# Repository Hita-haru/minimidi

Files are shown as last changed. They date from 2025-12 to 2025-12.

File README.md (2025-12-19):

# Little mini midi
## Description of this project.
This is my first midi keyboard.  
I used to https://blueprint.hackclub.com/starter-projects/midi as a reference.  

I was thinking I wish I could making songs with midi keyboard that graphical and useful.
So I maked this midi keyboard.

## Screenshots
Schematic  
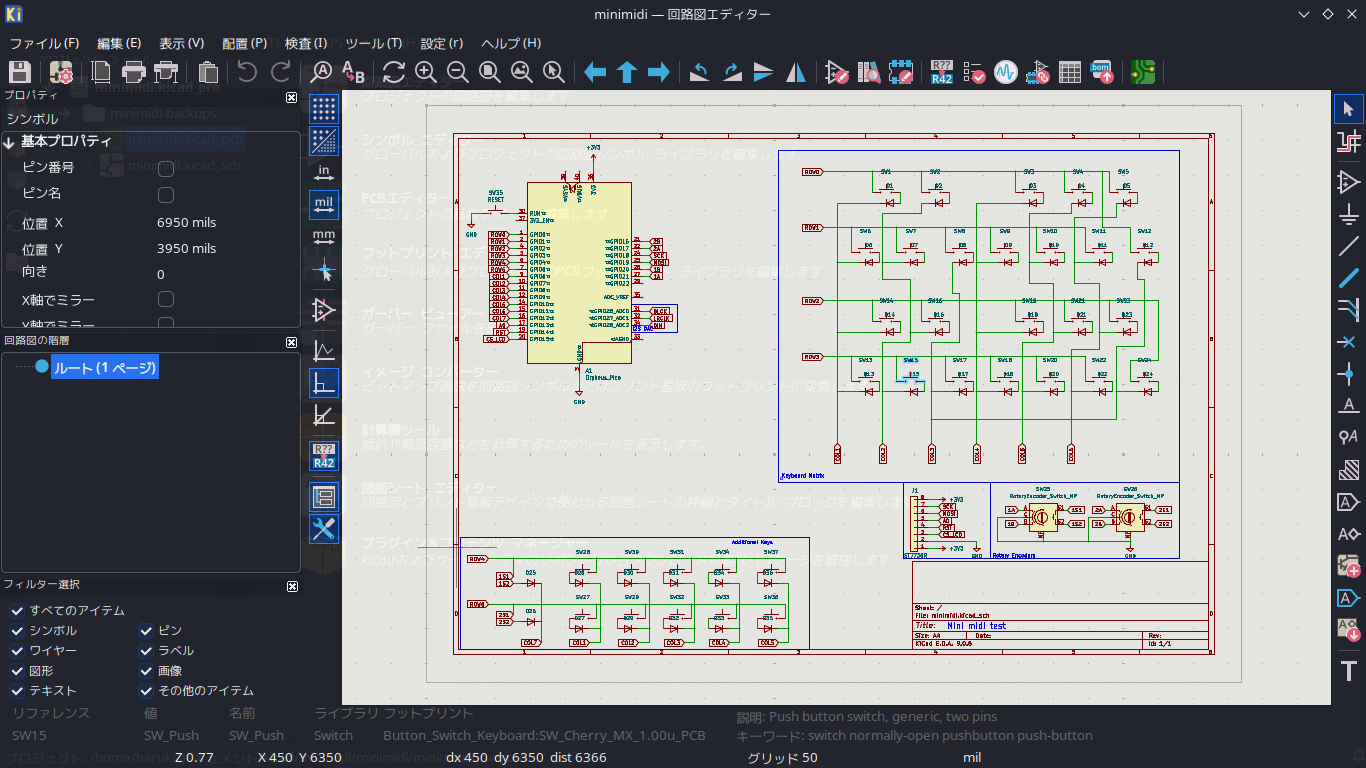
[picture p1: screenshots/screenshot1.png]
Kicad schematic screenshot
  
PCB(Layout)  
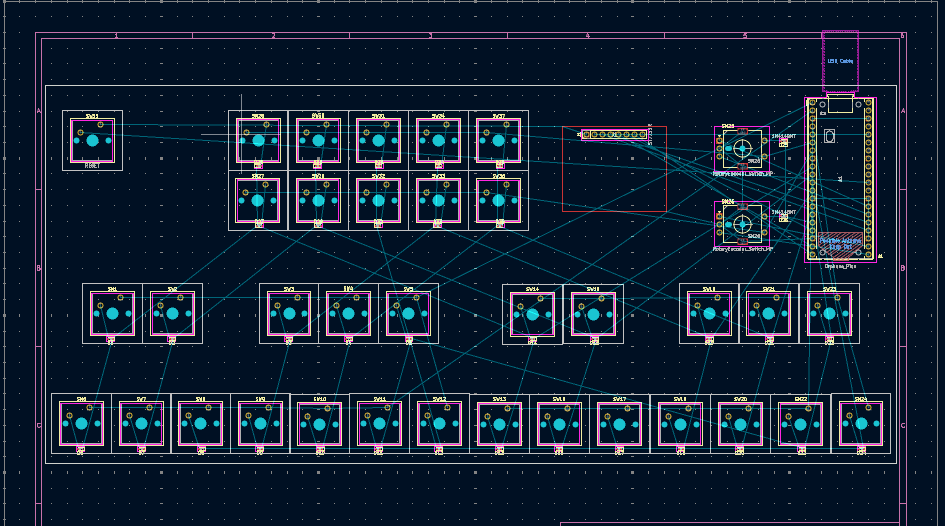
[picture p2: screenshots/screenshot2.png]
Kicad PCB screenshot
  
PCB(Final version)  
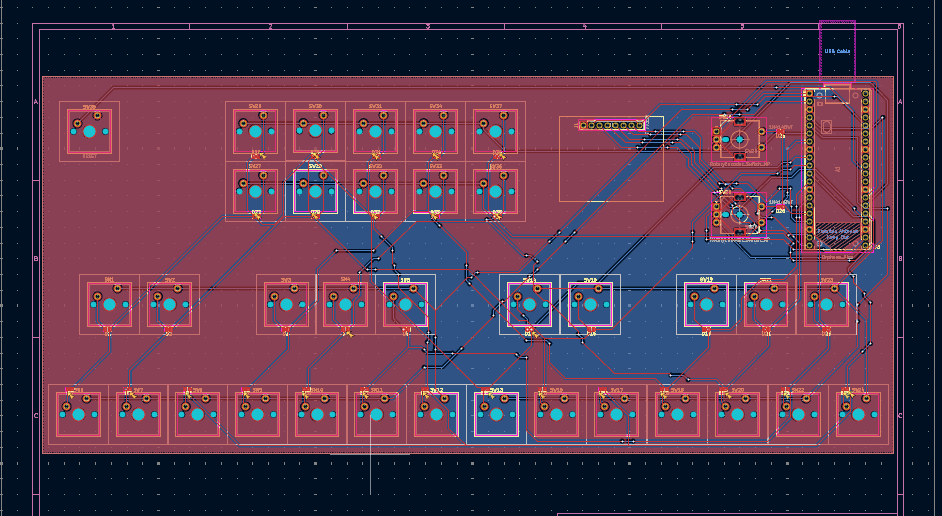
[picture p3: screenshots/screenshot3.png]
Kicad PCB screenshot
  
Programming  
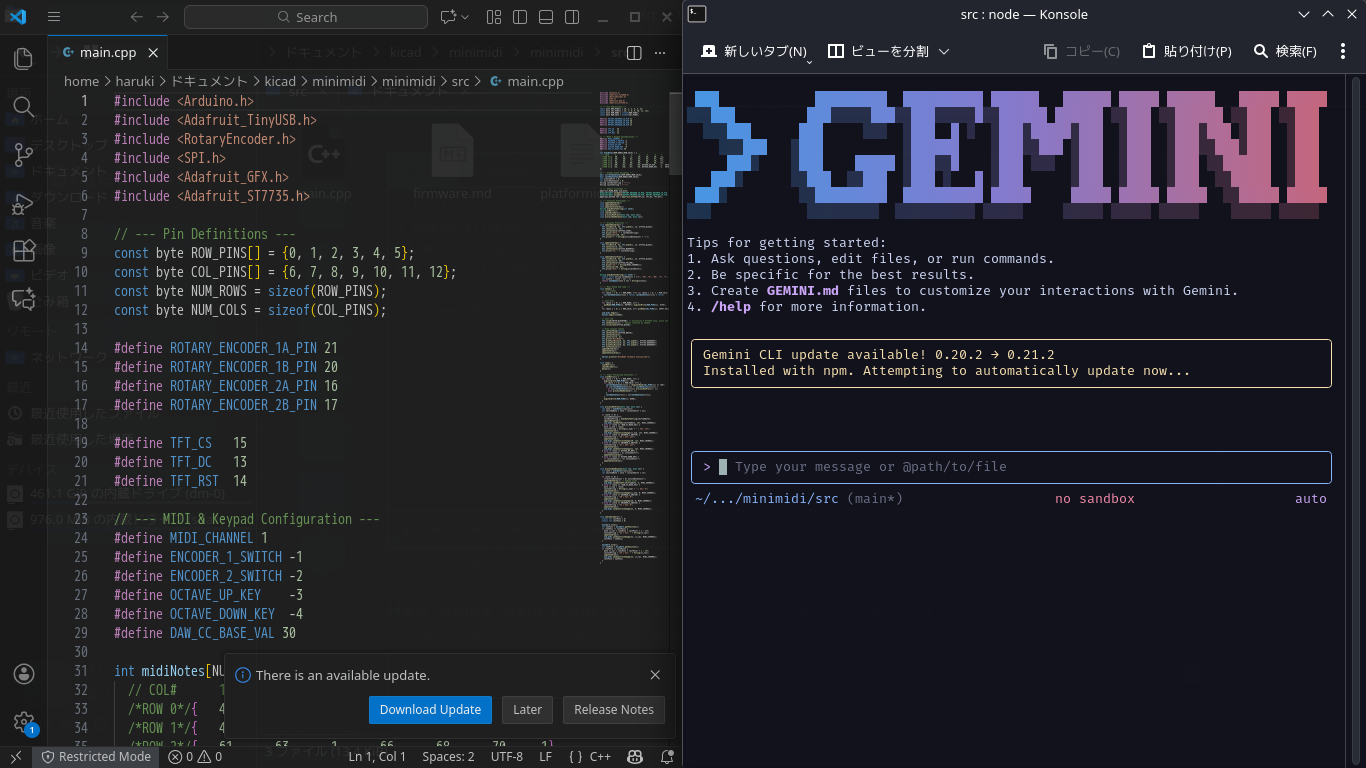
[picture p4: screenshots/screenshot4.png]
Programming
  
## Estimates
JLCPCB Estimate  
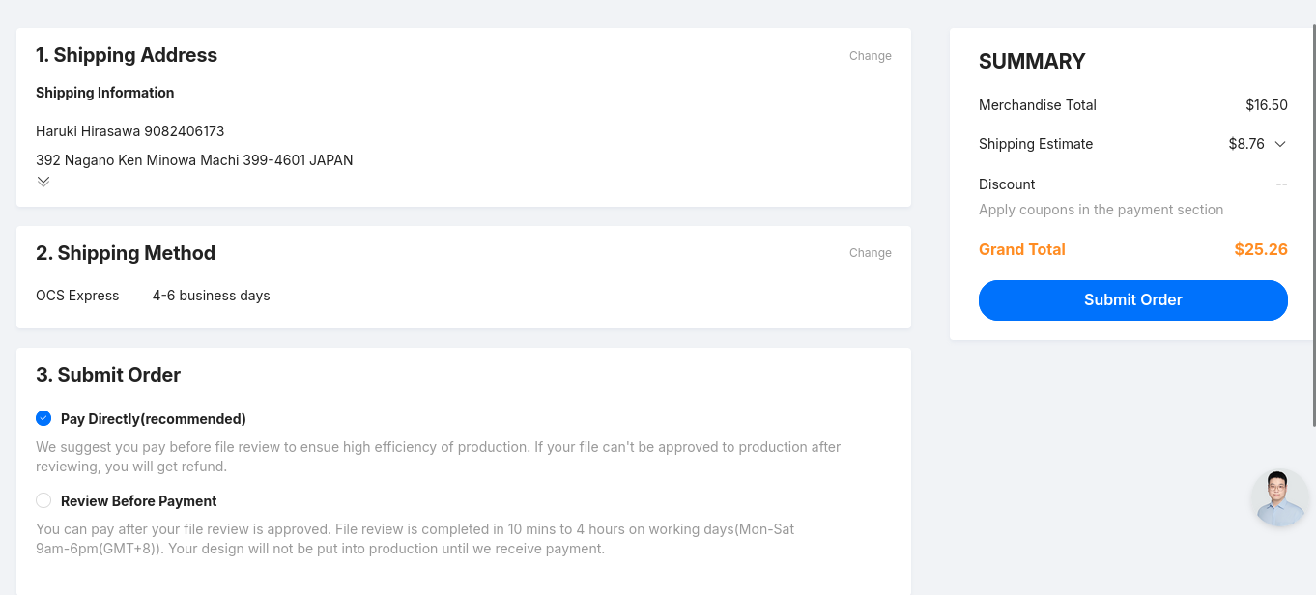
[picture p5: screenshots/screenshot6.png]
JLCPCB Estimate
  
LCSC Estimate  
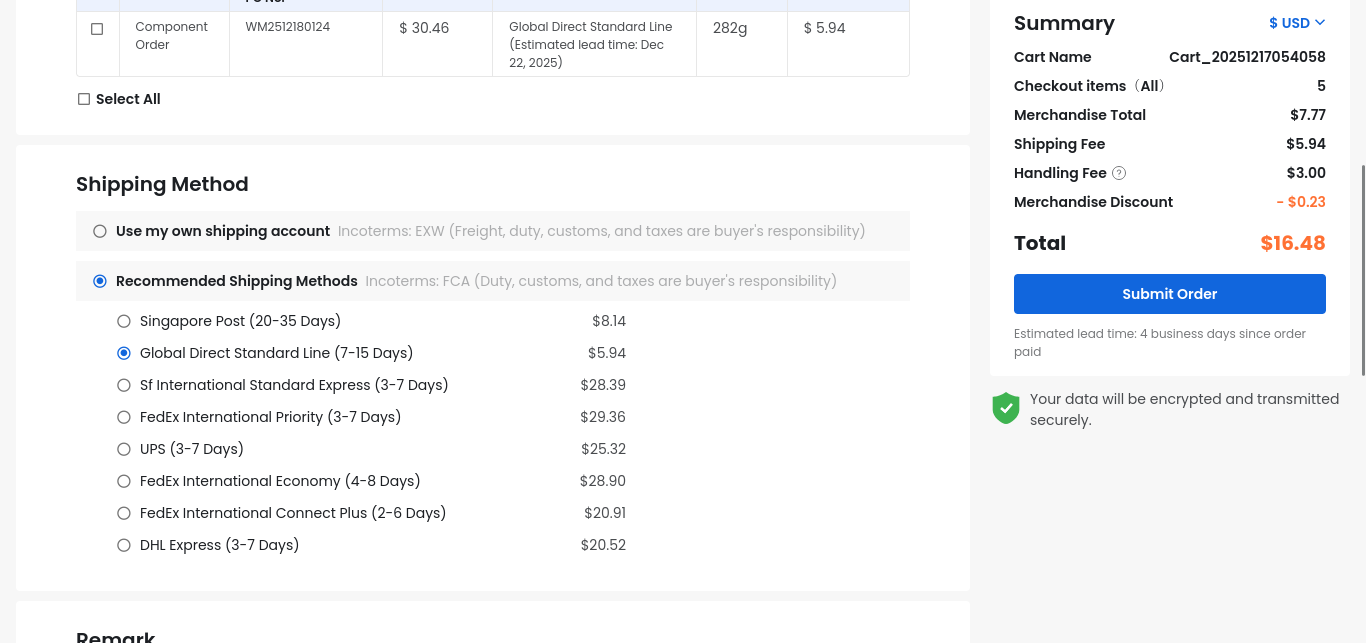
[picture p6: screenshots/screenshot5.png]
LCSC Estimate
  

## BOM
|Name |Quantity|
|---|---|
|Cherry MX Key  |35 |
|PinHeader 1x08 |1 |
|Diode |36 |
|RotaryEncoder  |2 |
|RP Pi Pico |1 |
|PinHeader 1x20 |2 |

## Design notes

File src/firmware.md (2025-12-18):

# MiniMIDIキーボード ファームウェアガイド

## 1. 概要

このドキュメントは、orpheus pico (Raspberry Pi Pico互換機) を使用した自作MIDIキーボードのファームウェアに関する使い方や仕様を説明するものです。

このファームウェアは以下の機能を持ちます:
- 4オクターブ範囲のMIDIノート出力
- オクターブUP/DOWN機能
- DAWコントロール用のMIDI CCボタン
- 2つのロータリーエンコーダーによるMIDI CC出力
- 操作内容をリアルタイムで表示するLCDディスプレイ機能

## 2. 必要なもの

### ハードウェア
- orpheus pico (またはRaspberry Pi Pico互換機)
- このプロジェクト用に作成されたキーボード基板
- ST7735 LCDディスプレイ
- PCと接続するためのUSBケーブル

### ソフトウェア
- [Visual Studio Code](https://code.visualstudio.com/)
- [PlatformIO IDE 拡張機能](https://platformio.org/platformio-ide)

## 3. インストールとファームウェアの書き込み

1.  **プロジェクトを開く**:
    Visual Studio Codeを起動し、「ファイル」>「フォルダーを開く...」からこのプロジェクトのディレクトリを選択します。

2.  **ライブラリの自動インストール**:
    プロジェクトを初めて開くと、PlatformIOが設定ファイル (`platformio.ini`) を読み込み、必要なライブラリ（USB MIDI、エンコーダー、LCDライブラリなど）を自動的にダウンロード・インストールします。

3.  **ファームウェアの書き込み**:
    - Picoの「BOOTSEL」ボタンを押しながら、PCにUSBケーブルで接続します。
    - VS Codeのターミナル（「ターミナル」>「新しいターミナル」）を開き、以下のコマンドを実行します。

    ```bash
    pio run --target upload
    ```
    - コンパイルと書き込みが自動的に実行されます。書き込みが完了すると、PicoはMIDIキーボードとしてPCに認識されます。

## 4. 機能と使い方

### キーボードとMIDIノート

- **鍵盤レイアウト**:
  - `ROW 0` & `ROW 2`: 黒鍵 (低オクターブ/高オクターブ)
  - `ROW 1` & `ROW 3`: 白鍵 (低オクターブ/高オクターブ)
- **オクターブ変更**:
  - **オクターブUP**: `ROW4, COL5` のキーを押します。 (最大+2)
  - **オクターブDOWN**: `ROW5, COL5` のキーを押します。 (最小-2)
  - 現在のオクターブ設定はLCDの下段に `Oct: ` として表示されます。

### DAWコントロールキー (MIDI CC)

`ROW4`と`ROW5`のキーは、DAWの機能を操作するためのコントロールチェンジ(CC)メッセージを送信します。キーを押している間ON (値:127)、離すとOFF (値:0) となるモーメンタリボタンとして機能します。

| キー (行, 列) | 送信されるCC番号 | 用途の例 |
| :--- | :--- | :--- |
| `ROW4, COL1` | CC 30 | トラック1のミュート/ソロ/録音アーム |
| `ROW4, COL2` | CC 31 | トラック2のミュート/ソロ/録音アーム |
| `ROW4, COL3` | CC 32 | トラック3のミュート/ソロ/録音アーム |
| `ROW4, COL4` | CC 33 | トラック4のミュート/ソロ/録音アーム |
| `ROW5, COL1` | CC 35 | トランスポート: 再生 |
| `ROW5, COL2` | CC 36 | トランスポート: 停止 |
| `ROW5, COL3` | CC 37 | トランスポート: 録音 |
| `ROW5, COL4` | CC 38 | メトロノーム ON/OFF |

### ロータリーエンコーダー

2つのエンコーダーは、回転と押し込みでCCメッセージを送信します。

| 操作 | 送信されるCC番号 | 値 | 用途の例 |
| :--- | :--- | :--- | :--- |
| **エンコーダー1 (上) 回転**  | CC 22 | 時計回り: 1, 反時計回り: 127 | 選択トラックのボリューム/パン調整 |
| **エンコーダー1 (上) 押込**  | CC 20 | 押した時: 127, 離した時: 0 | 選択トラックのミュート切り替え |
| **エンコーダー2 (下) 回転**  | CC 23 | 時計回り: 1, 反時計回り: 127 | マスターボリューム/パン調整 |
| **エンコーダー2 (下) 押込**  | CC 21 | 押した時: 127, 離した時: 0 | マスターミュート/エフェクトON/OFF |

### LCD情報パネル

LCDには3つのエリアがあり、リアルタイムで情報が更新されます。

- **上段 (Note)**: 最後に押したMIDIノート名と、現在同時に押されているキーの数を表示します。
  - 例: `Note: C#4 (2)`
- **中段 (CC)**: 最後に操作したエンコーダーやボタンのCC情報を表示します。
  - 例: `CC: 22 | Val: 1`
- **下段 (Status)**: 現在のMIDIチャンネルとオクターブ設定を表示します。
  - 例: `Ch:1 Oct:0`

## 5. トラブルシューティング

- **LCDが表示されない、または表示がおかしい**:
  ST7735 LCDにはいくつかの種類があります。`src/main.cpp`の`setup()`関数内にある以下の行を修正してみてください。
  ```cpp
  // この行の...
  tft.initR(INITR_BLACKTAB);
  
  // INITR_BLACKTAB の部分を、お使いのLCDに合わせて以下のように変更
  // tft.initR(INITR_GREENTAB);
  // tft.initR(INITR_REDTAB);
  ```
  また、画面の向きが正しくない場合は、すぐ下にある `tft.setRotation(1);` の数値を `0`, `2`, `3` のいずれかに変更して試してください。

- **キーやエンコーダーの動作がおかしい**:
  以下のコマンドでシリアルモニターを起動すると、PC側で詳細なデバッグログを確認できます。
  ```bash
  pio device monitor
  ```
  これにより、どのキーが認識され、どのようなMIDIメッセージが生成されているかを追跡できます。

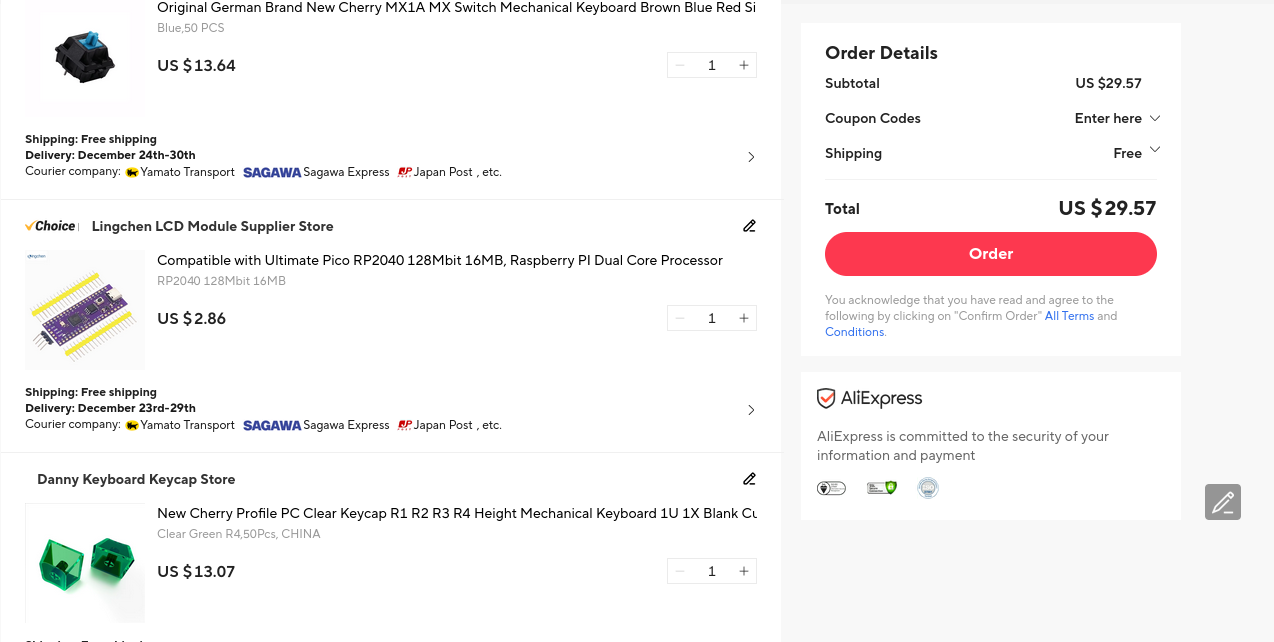
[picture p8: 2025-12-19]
screenshots/screenshot7.png

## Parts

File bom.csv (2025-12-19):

ID | 指定子 | フットプリント | 数量 | 名称 | 供給業者、参考資料
1 | SW28,SW33,SW24,SW13,SW32,SW12,SW31,SW19,SW20,SW30,SW23,SW16,SW17,SW6,SW21,SW27,SW10,SW3,SW34,SW14,SW11,SW36,SW18,SW1,SW8,SW9,SW15,SW7,SW22,SW5,SW37,SW4,SW2,SW29 | SW_Cherry_MX_1.00u_PCB | 34 | SW_Push
2 | D21,D3,D22,D29,D35,D5,D25,D15,D17,D30,D24,D4,D34,D26,D19,D6,D36,D10,D28,D2,D12,D20,D31,D23,D18,D33,D32,D11,D13,D9,D14,D27,D16,D8,D1,D7 | D_SOD-523 | 36 | 1N4148WT
3 | SW25,SW26 | RotaryEncoder_Alps_EC11E-Switch_Vertical_H20mm_MountingHoles | 2 | RotaryEncoder_Switch_MP
4 | J1 | PinHeader_1x08_P2.54mm_Vertical | 1 | ST7735R
5 | SW35 | SW_Cherry_MX_1.00u_PCB | 1 | RESET
6 | A1 | RaspberryPi_Pico_Common_THT | 1 | Orpheus_Pico
7 |  | Key_cap | 35
7 |  | PinHeader_1x20;2;;

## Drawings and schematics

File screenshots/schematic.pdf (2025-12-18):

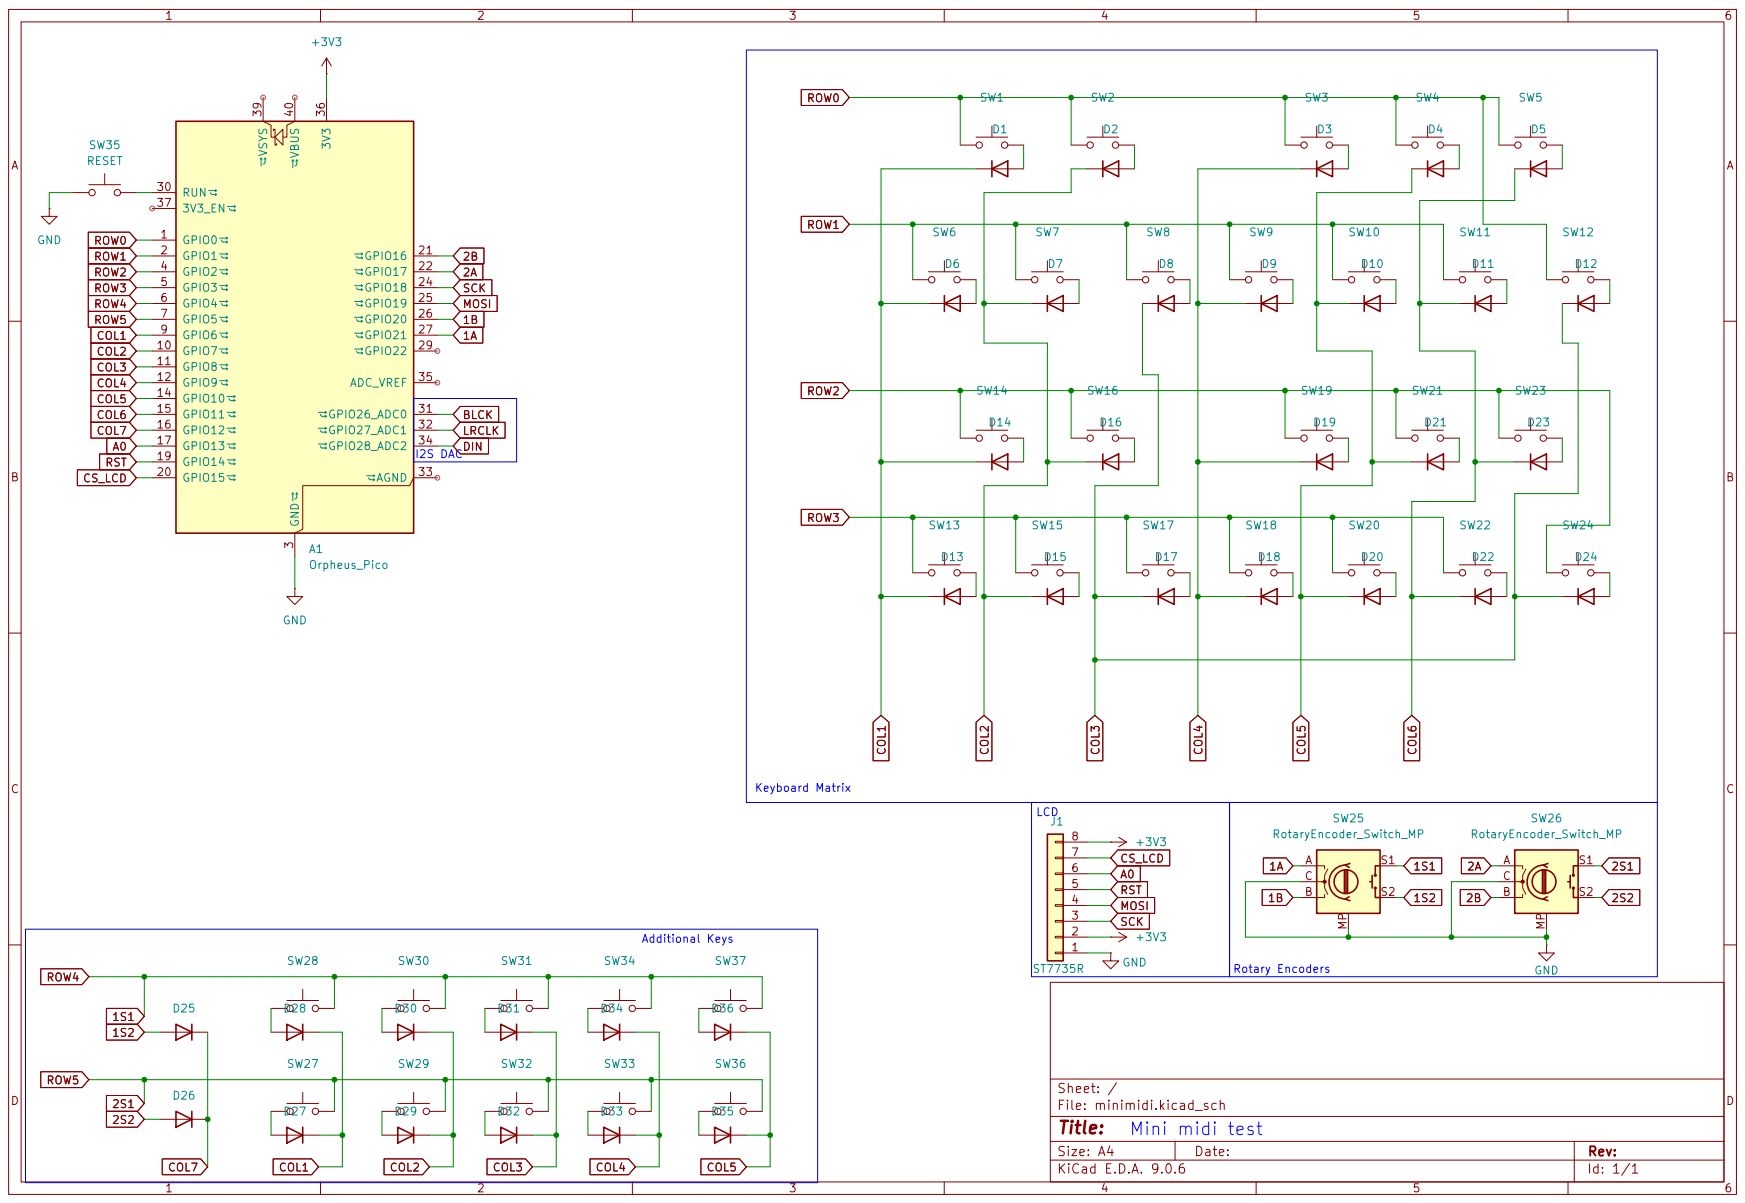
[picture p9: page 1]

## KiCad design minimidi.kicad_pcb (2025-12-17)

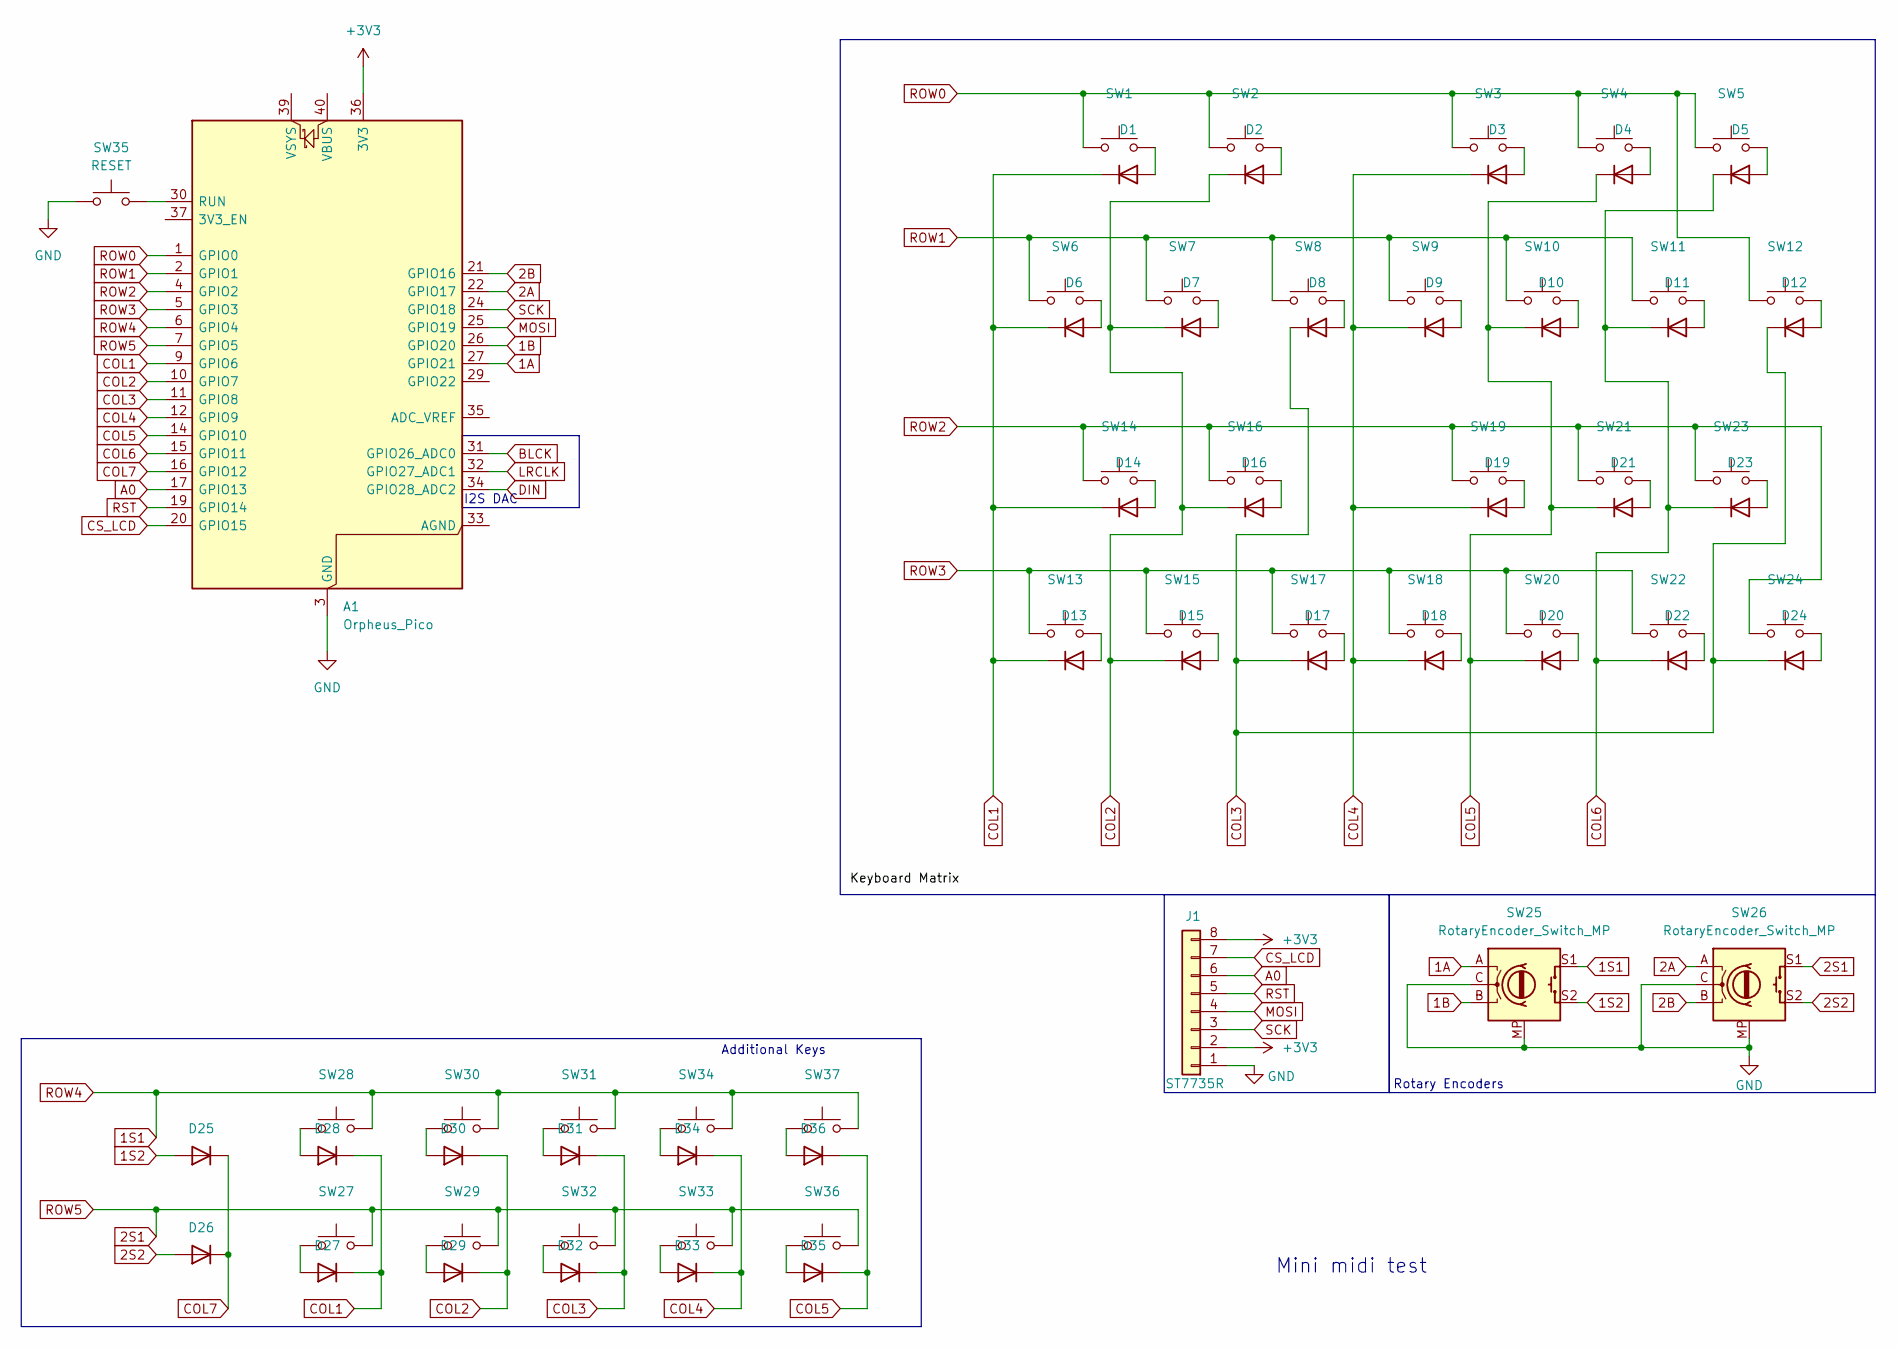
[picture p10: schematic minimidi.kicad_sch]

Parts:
A1: Orpheus_Pico; RaspberryPi_Pico_Common_THT
D1, D2, D3, D4, D5, D6, D7, D8, D9, D10, D11, D12, D13, D14, D15, D16, D17, D18, D19, D20, D21, D22, D23, D24, D25, D26, D27, D28, D29, D30, D31, D32, D33, D34, D35, D36: 1N4148WT; D_SOD-523
J1: ST7735R; PinHeader_1x08_P2.54mm_Vertical
SW1, SW2, SW3, SW4, SW5, SW6, SW7, SW8, SW9, SW10, SW11, SW12, SW13, SW14, SW15, SW16, SW17, SW18, SW19, SW20, SW21, SW22, SW23, SW24, SW27, SW28, SW29, SW30, SW31, SW32, SW33, SW34, SW36, SW37: SW_Push; SW_Cherry_MX_1.00u_PCB
SW25, SW26: RotaryEncoder_Switch_MP; RotaryEncoder_Alps_EC11E-Switch_Vertical_H20mm_MountingHoles
SW35: RESET; SW_Cherry_MX_1.00u_PCB

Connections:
1A: A1.27 (GPIO21), SW25.A
1B: A1.26 (GPIO20), SW25.B
1S1: A1.6 (GPIO4), SW25.S1, SW28.2, SW30.2, SW31.2, SW34.2, SW37.2
1S2: D25.2 (A), SW25.S2
2A: A1.22 (GPIO17), SW26.A
2B: A1.21 (GPIO16), SW26.B
2S1: A1.7 (GPIO5), SW26.S1, SW27.2, SW29.2, SW32.2, SW33.2, SW36.2
2S2: D26.2 (A), SW26.S2
+3V3: A1.36 (3V3), J1.2, J1.8
A0: A1.17 (GPIO13), J1.6
BLCK: A1.31 (GPIO26_ADC0)
COL1: A1.9 (GPIO6), D1.1 (K), D6.1 (K), D13.1 (K), D14.1 (K), D27.1 (K), D28.1 (K)
COL2: A1.10 (GPIO7), D2.1 (K), D7.1 (K), D15.1 (K), D16.1 (K), D29.1 (K), D30.1 (K)
COL3: A1.11 (GPIO8), D8.1 (K), D12.1 (K), D17.1 (K), D24.1 (K), D31.1 (K), D32.1 (K)
COL4: A1.12 (GPIO9), D3.1 (K), D9.1 (K), D18.1 (K), D19.1 (K), D33.1 (K), D34.1 (K)
COL5: A1.14 (GPIO10), D4.1 (K), D10.1 (K), D20.1 (K), D21.1 (K), D35.1 (K), D36.1 (K)
COL6: A1.15 (GPIO11), D5.1 (K), D11.1 (K), D22.1 (K), D23.1 (K)
COL7: A1.16 (GPIO12), D25.1 (K), D26.1 (K)
CS_LCD: A1.20 (GPIO15), J1.7
DIN: A1.34 (GPIO28_ADC2)
GND: A1.3 (GND), A1.8 (GND), A1.13 (GND), A1.18 (GND), A1.23 (GND), A1.28 (GND), A1.38 (GND), J1.1, SW25.C, SW25.MP, SW26.C, SW26.MP, SW35.1
LRCLK: A1.32 (GPIO27_ADC1)
MOSI: A1.25 (GPIO19), J1.4
unnamed: A1.30 (RUN), SW35.2
unnamed: D1.2 (A), SW1.2
unnamed: D2.2 (A), SW2.2
unnamed: D3.2 (A), SW3.2
unnamed: D4.2 (A), SW4.2
unnamed: D5.2 (A), SW5.2
unnamed: D6.2 (A), SW6.2
unnamed: D7.2 (A), SW7.2
unnamed: D8.2 (A), SW8.2
unnamed: D9.2 (A), SW9.2
unnamed: D10.2 (A), SW10.2
unnamed: D11.2 (A), SW11.2
unnamed: D12.2 (A), SW12.2
unnamed: D13.2 (A), SW13.2
unnamed: D14.2 (A), SW14.2
unnamed: D15.2 (A), SW15.2
unnamed: D16.2 (A), SW16.2
unnamed: D17.2 (A), SW17.2
unnamed: D18.2 (A), SW18.2
unnamed: D19.2 (A), SW19.2
unnamed: D20.2 (A), SW20.2
unnamed: D21.2 (A), SW21.2
unnamed: D22.2 (A), SW22.2
unnamed: D23.2 (A), SW23.2
unnamed: D24.2 (A), SW24.2
unnamed: D27.2 (A), SW27.1
unnamed: D28.2 (A), SW28.1
unnamed: D29.2 (A), SW29.1
unnamed: D30.2 (A), SW30.1
unnamed: D31.2 (A), SW31.1
unnamed: D32.2 (A), SW32.1
unnamed: D33.2 (A), SW33.1
unnamed: D34.2 (A), SW34.1
unnamed: D35.2 (A), SW36.1
unnamed: D36.2 (A), SW37.1
ROW0: A1.1 (GPIO0), SW1.1, SW2.1, SW3.1, SW4.1, SW5.1, SW12.1
ROW1: A1.2 (GPIO1), SW6.1, SW7.1, SW8.1, SW9.1, SW10.1, SW11.1
ROW2: A1.4 (GPIO2), SW14.1, SW16.1, SW19.1, SW21.1, SW23.1, SW24.1
ROW3: A1.5 (GPIO3), SW13.1, SW15.1, SW17.1, SW18.1, SW20.1, SW22.1
RST: A1.19 (GPIO14), J1.5
SCK: A1.24 (GPIO18), J1.3

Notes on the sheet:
Mini midi test
I2S DAC
Additional Keys
Rotary Encoders

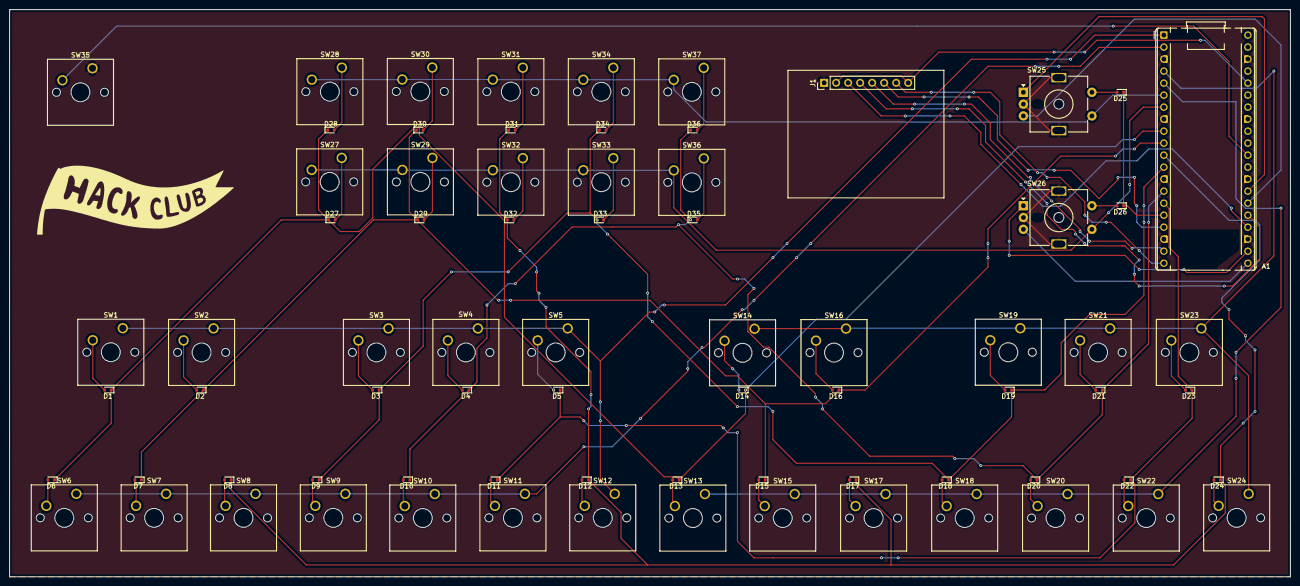
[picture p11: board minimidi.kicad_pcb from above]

Board: 2 copper layers, 271.0 x 120.0 mm, 75 parts (0 on the bottom side), 61 nets.

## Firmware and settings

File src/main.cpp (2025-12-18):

#include <Arduino.h>
#include <Adafruit_TinyUSB.h>
#include <RotaryEncoder.h>
#include <SPI.h>
#include <Adafruit_GFX.h>
#include <Adafruit_ST7735.h>

// --- Pin Definitions ---
const byte ROW_PINS[] = {0, 1, 2, 3, 4, 5};
const byte COL_PINS[] = {6, 7, 8, 9, 10, 11, 12};
const byte NUM_ROWS = sizeof(ROW_PINS);
const byte NUM_COLS = sizeof(COL_PINS);

#define ROTARY_ENCODER_1A_PIN 21
#define ROTARY_ENCODER_1B_PIN 20
#define ROTARY_ENCODER_2A_PIN 16
#define ROTARY_ENCODER_2B_PIN 17

#define TFT_CS   15
#define TFT_DC   13
#define TFT_RST  14

// --- MIDI & Keypad Configuration ---
#define MIDI_CHANNEL 1
#define ENCODER_1_SWITCH -1
#define ENCODER_2_SWITCH -2
#define OCTAVE_UP_KEY    -3
#define OCTAVE_DOWN_KEY  -4
#define DAW_CC_BASE_VAL 30

int midiNotes[NUM_ROWS][NUM_COLS] = {
  // COL#      1,      2,      3,      4,      5,      6,    7
  /*ROW 0*/{   49,     51,    -1,     54,     56,     58,   -1},
  /*ROW 1*/{   48,     50,    52,     53,     55,     57,   59},
  /*ROW 2*/{   61,     63,    -1,     66,     68,     70,   -1},
  /*ROW 3*/{   60,     62,    64,     65,     67,     69,   71},
  /*ROW 4*/{  -30,    -31,   -32,    -33, OCTAVE_UP_KEY,    -1,  ENCODER_1_SWITCH},
  /*ROW 5*/{  -35,    -36,   -37,    -38, OCTAVE_DOWN_KEY,  -1,  ENCODER_2_SWITCH}
};

// --- Global State Variables ---
bool currentKeyStates[NUM_ROWS][NUM_COLS];
bool lastKeyStates[NUM_ROWS][NUM_COLS];
int octaveShift = 0;
int activeNoteCount = 0;
String lastNoteString = "---";
String lastCCString = "---";

// --- Object Instances ---
Adafruit_USBD_MIDI usb_midi;
RotaryEncoder encoder1(ROTARY_ENCODER_1A_PIN, ROTARY_ENCODER_1B_PIN, RotaryEncoder::LatchMode::FOUR3);
RotaryEncoder encoder2(ROTARY_ENCODER_2A_PIN, ROTARY_ENCODER_2B_PIN, RotaryEncoder::LatchMode::FOUR3);
Adafruit_ST7735 tft = Adafruit_ST7735(TFT_CS, TFT_DC, TFT_RST);

// --- Function Prototypes ---
void updateNoteArea();
void updateCCArea();
void updateStatusArea();
String midiNoteToString(int note);
void scanMatrix();
void checkEncoders();
void processKeyPress(byte row, byte col);
void processKeyRelease(byte row, byte col);


// --- Display Functions ---
void updateNoteArea() {
  tft.fillRect(0, 25, tft.width(), 12, ST7735_BLACK);
  tft.setCursor(5, 25);
  tft.setTextColor(ST7735_CYAN);
  tft.print("Note: " + lastNoteString);
  tft.setCursor(110, 25);
  tft.print("(" + String(activeNoteCount) + ")");
}

void updateCCArea() {
  tft.fillRect(0, 55, tft.width(), 12, ST7735_BLACK);
  tft.setCursor(5, 55);
  tft.setTextColor(ST7735_MAGENTA);
  tft.print("CC: " + lastCCString);
}

void updateStatusArea() {
  tft.fillRect(0, 85, tft.width(), 12, ST7735_BLACK);
  tft.setCursor(5, 85);
  tft.setTextColor(ST7735_YELLOW);
  tft.print("Ch:" + String(MIDI_CHANNEL));
  tft.setCursor(80, 85);
  tft.print("Oct:" + String(octaveShift));
}

String midiNoteToString(int note) {
  static const String noteNames[] = {"C", "C#", "D", "D#", "E", "F", "F#", "G", "G#", "A", "A#", "B"};
  int octave = (note / 12) - 1;
  return noteNames[note % 12] + String(octave);
}

// --- Main Setup and Loop ---
void setup() {
  // Init states
  for (byte r = 0; r < NUM_ROWS; r++) for (byte c = 0; c < NUM_COLS; c++) {
    currentKeyStates[r][c] = false; lastKeyStates[r][c] = false;
  }
  
  // Init Pins
  for (byte i = 0; i < NUM_ROWS; i++) {
    pinMode(ROW_PINS[i], OUTPUT); digitalWrite(ROW_PINS[i], HIGH);
  }
  for (byte i = 0; i < NUM_COLS; i++) pinMode(COL_PINS[i], INPUT_PULLUP);

  usb_midi.begin();
  Serial.begin(115200);

  // Init LCD
  tft.initR(INITR_BLACKTAB); // Initialize a ST7735S chip, black tab
  tft.setRotation(1); // Adjust rotation as needed
  tft.fillScreen(ST7735_BLACK);

  // Draw initial layout
  tft.setTextWrap(false);
  tft.setTextColor(ST7735_WHITE);
  tft.setTextSize(2);
  tft.setCursor(5, 5);
  tft.print("MiniMIDI");
  tft.drawFastHLine(0, 22, tft.width(), ST7735_DARKGREY);
  tft.drawFastHLine(0, 52, tft.width(), ST7735_DARKGREY);
  tft.drawFastHLine(0, 82, tft.width(), ST7735_DARKGREY);
  tft.setTextSize(1);
  updateNoteArea();
  updateCCArea();
  updateStatusArea();
  
  Serial.println("MiniMIDI Firmware Initialized");
}

void loop() {
  scanMatrix();
  checkEncoders();
  delay(1); 
}

// --- Input Processing Functions ---
void scanMatrix() {
  for (byte r = 0; r < NUM_ROWS; r++) {
    digitalWrite(ROW_PINS[r], LOW);
    for (byte c = 0; c < NUM_COLS; c++) {
      currentKeyStates[r][c] = (digitalRead(COL_PINS[c]) == LOW);
      if (currentKeyStates[r][c] != lastKeyStates[r][c]) {
        if (currentKeyStates[r][c]) processKeyPress(r, c);
        else processKeyRelease(r, c);
      }
      lastKeyStates[r][c] = currentKeyStates[r][c];
    }
    digitalWrite(ROW_PINS[r], HIGH);
  }
}

void processKeyPress(byte row, byte col) {
  int note = midiNotes[row][col];
  int shiftedNote = note + (octaveShift * 12);

  if (note >= 0) {
    activeNoteCount++;
    lastNoteString = midiNoteToString(shiftedNote);
    updateNoteArea();
    usb_midi.sendNoteOn(shiftedNote, 127, MIDI_CHANNEL);
  } else if (note <= -DAW_CC_BASE_VAL) {
    byte cc_num = -note;
    lastCCString = String(cc_num) + " | Val: 127";
    updateCCArea();
    usb_midi.sendControlChange(cc_num, 127, MIDI_CHANNEL);
  } else if (note == ENCODER_1_SWITCH) {
    lastCCString = "20 | Val: 127";
    updateCCArea();
    usb_midi.sendControlChange(20, 127, MIDI_CHANNEL);
  } else if (note == ENCODER_2_SWITCH) {
    lastCCString = "21 | Val: 127";
    updateCCArea();
    usb_midi.sendControlChange(21, 127, MIDI_CHANNEL);
  } else if (note == OCTAVE_UP_KEY) {
    if (octaveShift < 2) octaveShift++;
    updateStatusArea();
  } else if (note == OCTAVE_DOWN_KEY) {
    if (octaveShift > -2) octaveShift--;
    updateStatusArea();
  }
}

void processKeyRelease(byte row, byte col) {
  int note = midiNotes[row][col];
  int shiftedNote = note + (octaveShift * 12);

  if (note >= 0) {
    if(activeNoteCount > 0) activeNoteCount--;
    updateNoteArea(); // Update count
    usb_midi.sendNoteOff(shiftedNote, 0, MIDI_CHANNEL);
  } else if (note <= -DAW_CC_BASE_VAL) {
    byte cc_num = -note;
    lastCCString = String(cc_num) + " | Val: 0";
    updateCCArea();
    usb_midi.sendControlChange(cc_num, 0, MIDI_CHANNEL);
  } else if (note == ENCODER_1_SWITCH) {
    lastCCString = "20 | Val: 0";
    updateCCArea();
    usb_midi.sendControlChange(20, 0, MIDI_CHANNEL);
  } else if (note == ENCODER_2_SWITCH) {
    lastCCString = "21 | Val: 0";
    updateCCArea();
    usb_midi.sendControlChange(21, 0, MIDI_CHANNEL);
  }
}

void checkEncoders() {
  static int lastPos1 = 0;
  static int lastPos2 = 0;

  encoder1.tick();
  int newPos1 = encoder1.getPosition();
  if (newPos1 != lastPos1) {
    byte cc_val = (newPos1 > lastPos1) ? 1 : 127;
    lastCCString = "22 | Val: " + String(cc_val);
    updateCCArea();
    usb_midi.sendControlChange(22, cc_val, MIDI_CHANNEL);
    lastPos1 = newPos1;
  }

  encoder2.tick();
  int newPos2 = encoder2.getPosition();
  if (newPos2 != lastPos2) {
    byte cc_val = (newPos2 > lastPos2) ? 1 : 127;
    lastCCString = "23 | Val: " + String(cc_val);
    updateCCArea();
    usb_midi.sendControlChange(23, cc_val, MIDI_CHANNEL);
    lastPos2 = newPos2;
  }
}

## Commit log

2025-12-16 Making filesystems
    [minimidi.kicad_pcb, minimidi.kicad_sch]
2025-12-16 Making PCBs
    [minimidi.kicad_pcb, minimidi.kicad_sch]
2025-12-18 Making firmware
    [bom.csv, minimidi.kicad_sch, pins.csv]
2025-12-18 Add screenshots
    [bom.csv]
2025-12-19 Updating README.md
    [bom.csv]
